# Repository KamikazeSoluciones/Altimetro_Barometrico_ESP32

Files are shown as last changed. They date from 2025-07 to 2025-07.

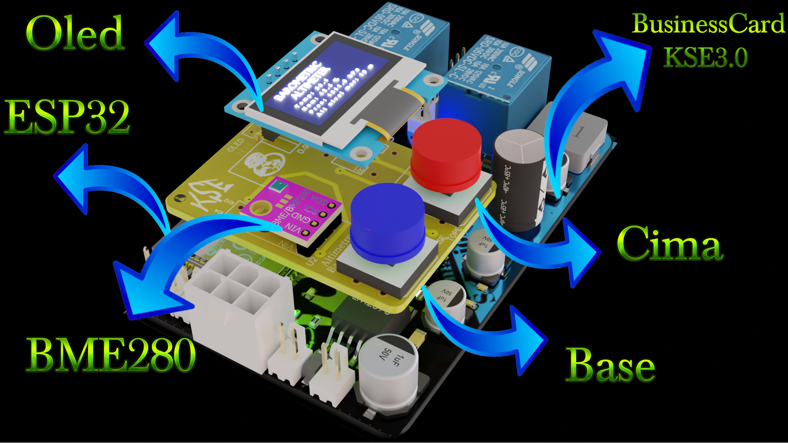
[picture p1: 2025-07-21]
Altimetro.png

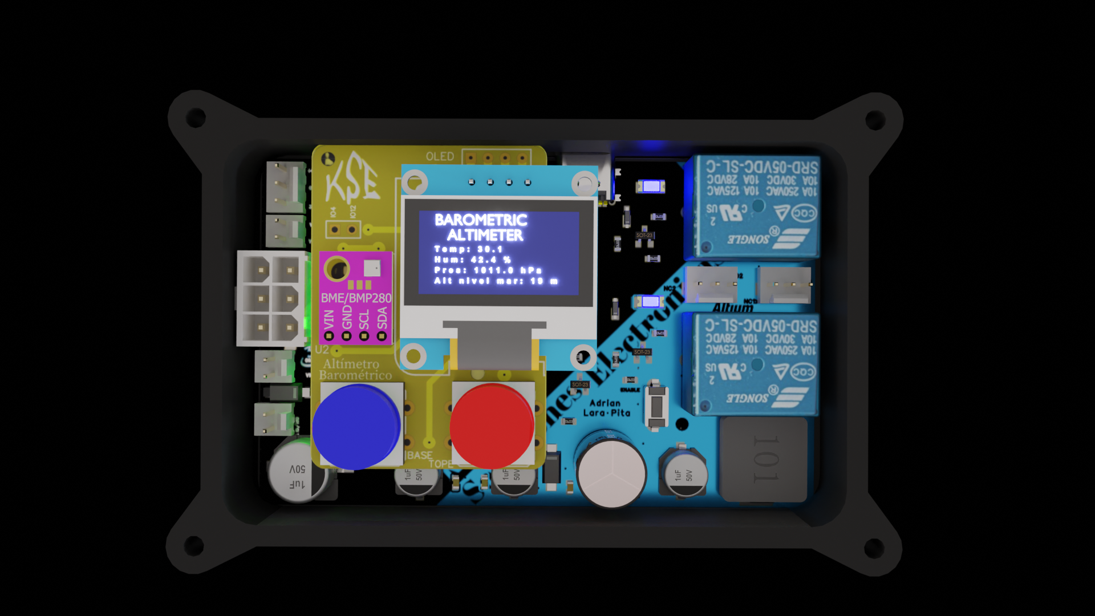
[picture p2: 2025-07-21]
render 3.png

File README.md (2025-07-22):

Altímetro Barométrico on ESP32

Este dispositivo es un proyecto experimental de altímetro barométrico diseñado para estimar la altura entre 
dos puntos mediante la diferencia de presión atmosférica, utilizando un sensor BME280 y un microcontrolador ESP32. 
La lectura se muestra en una pantalla OLED.

Este dispositivo fue probado en terreno en varios puntos icónicos de París: 
Torre Eiffel 
Arco del Triunfo.
Museo de Louvre
Río Sena

🚀 Objetivo

Explorar el uso de sensores barométricos para medir alturas reales, como una evolución de métodos tradicionales 
(por ejemplo, estimar la altura de edificios según el número de pisos). Además, es un proyecto ideal para enseñar 
física, presión atmosférica y electrónica aplicada.

📸 Ejemplo de Medición en la Torre Eiffel

- Presión atmosférica marcada en la base: 1017,6 hPa  
- Presión atmosférica marcada en el segundo piso: 1003,83 hPa  
- Altura estimada: 113,1 m  
- Altura oficial: 116 m  

🧰 Componentes utilizados


- ESP32 (Business Card Green Edition)
- Sensor BME280 (I2C)
- Pantalla OLED 128x64 (SSD1306)
- Pulsadores N.O.
- Power Bank
- Enclosure 3D impreso (modelado en SolidWorks)

⚙️ Funcionamiento

1. Al encender el dispositivo, se muestra la presión y temperatura actuales.
2. Se presiona el botón "Start" para registrar la presión inicial.
3. En otro punto, se presiona el botón "End" para registrar la nueva presión.
4. El sistema calcula la altura estimada según la fórmula barométrica.
5. Los datos se muestran en la pantalla Oled.

🧮 Fórmula usada



🛠️ Para compilar

1. Abre el código con Arduino IDE o PlatformIO.
2. Instala las siguientes bibliotecas:

   - Adafruit BME280
   - Adafruit Sensor
   - Adafruit SSD1306
3. Ajusta los pines I2C si es necesario.
4. Sube el código al ESP32 y listo.

📦 Impresión 3D
- El diseño incluye una tapa avellanada para tornillos M3.
- Archivos disponibles en formato `.step` y `.stl`.
  




✍️ Autor

Adrian Lara – Freelance en electrónica, diseño 3D y sistemas embebidos
🔗 Youtube: https://youtu.be/_3JePDyfMUw 
📞 +351 911 180 717

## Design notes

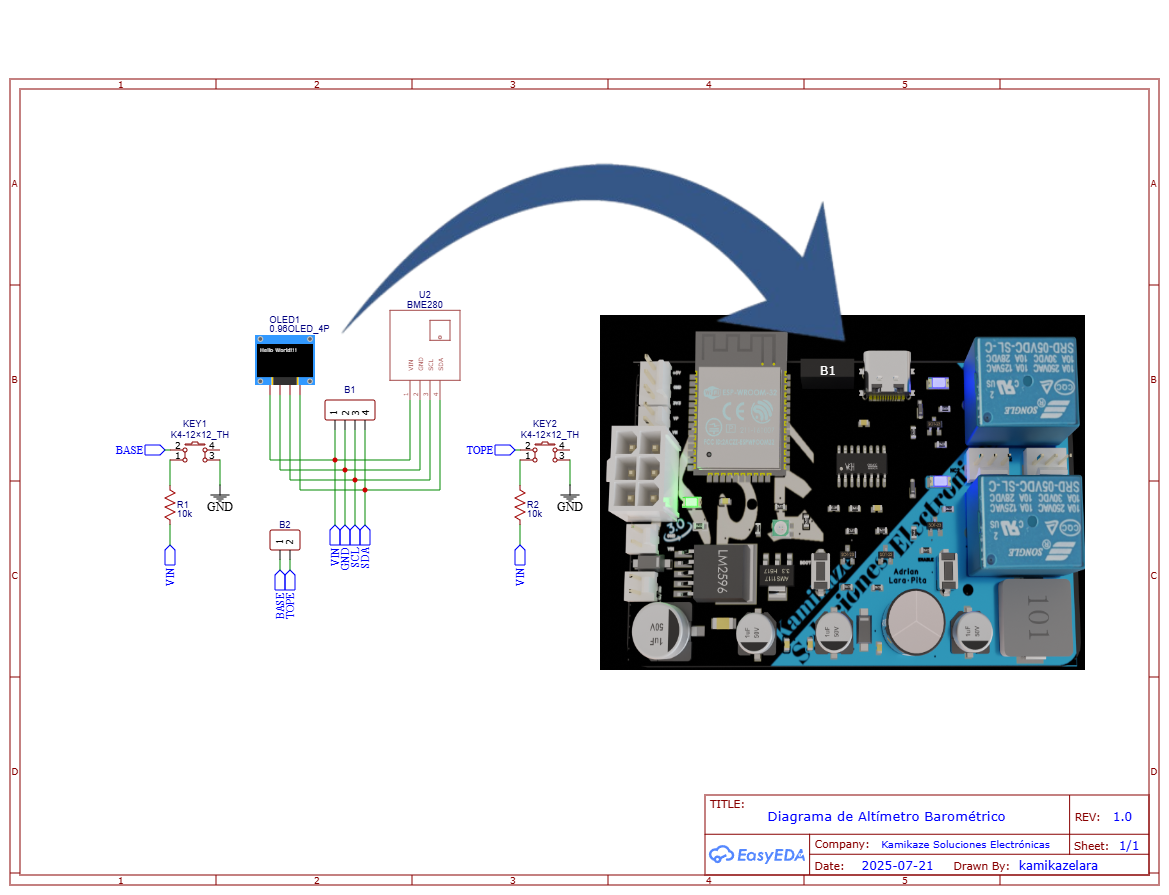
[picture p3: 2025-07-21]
Schematic_Altimetro-Barometrico_2025-07-21.png

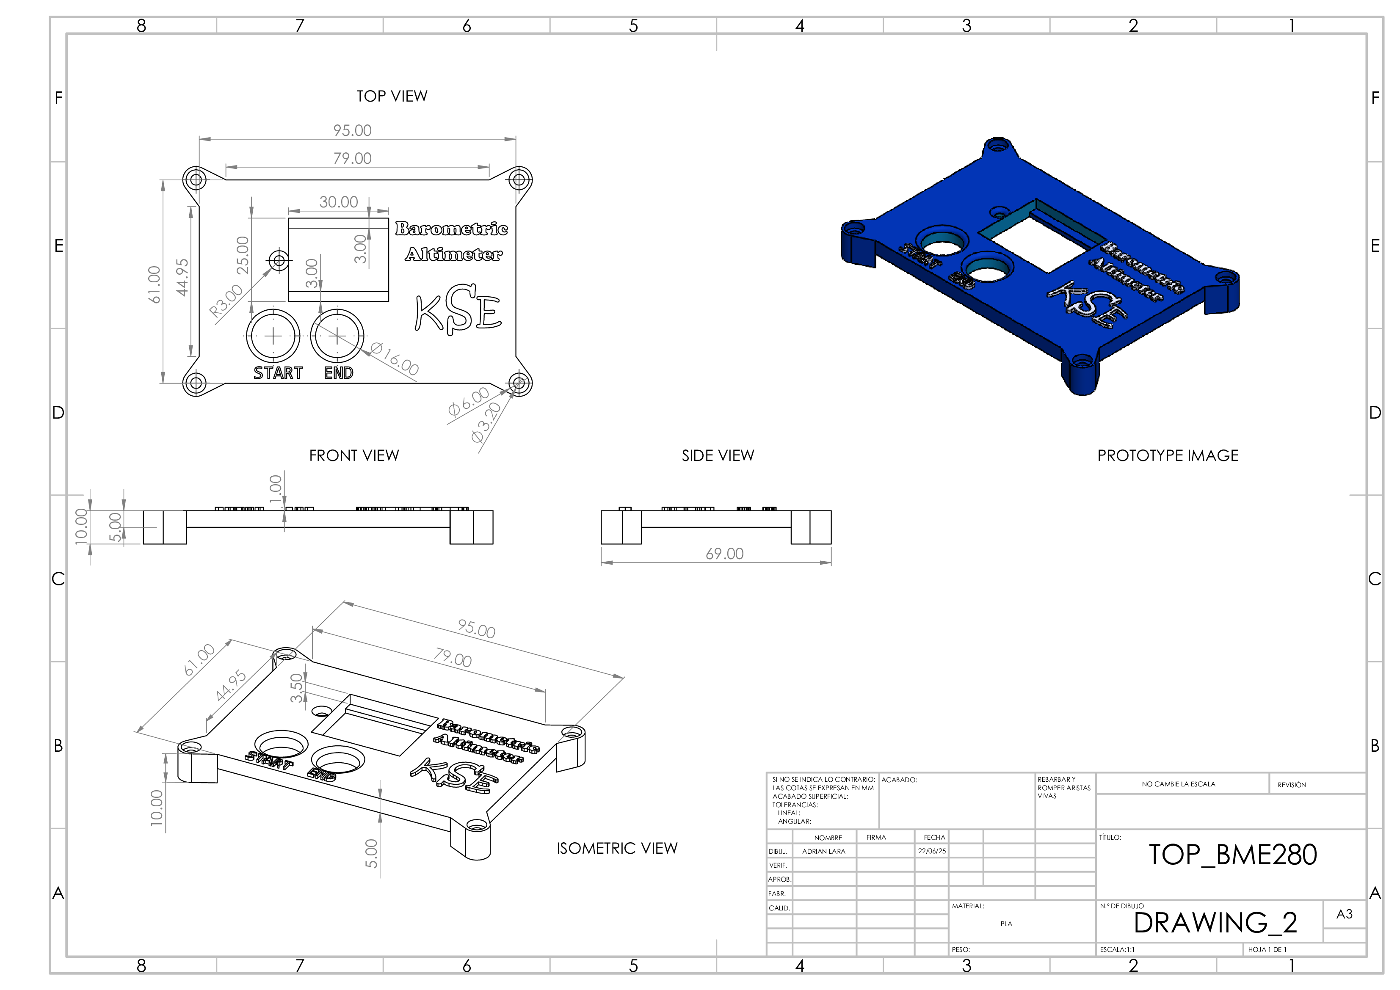
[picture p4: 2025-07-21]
Top_BME280.png

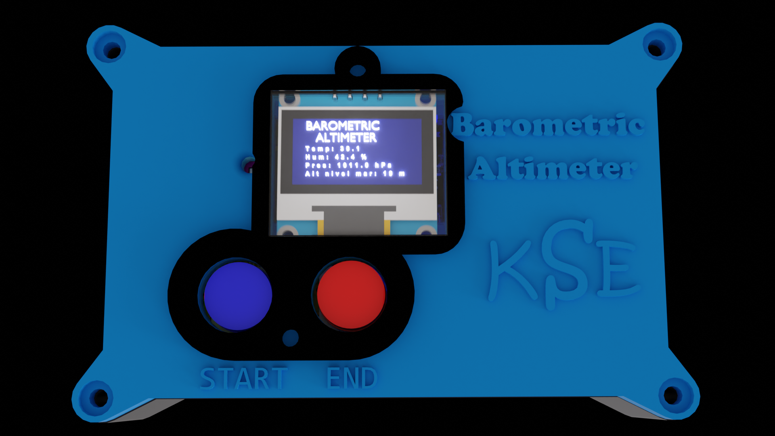
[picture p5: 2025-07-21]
render3.png

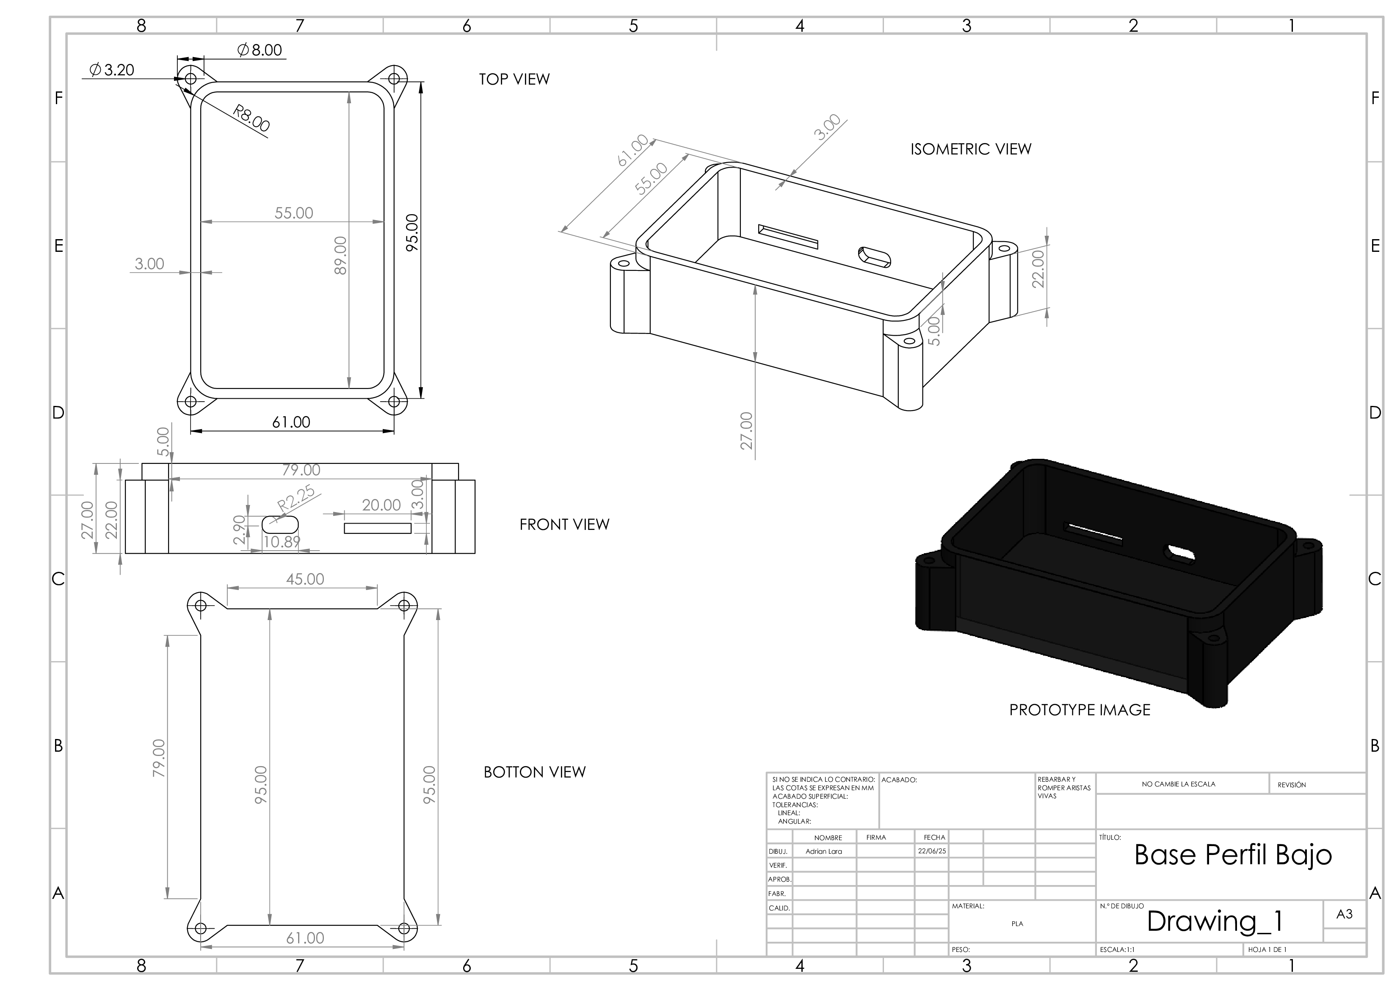
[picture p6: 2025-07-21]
Base._Perfil_Bajo.png

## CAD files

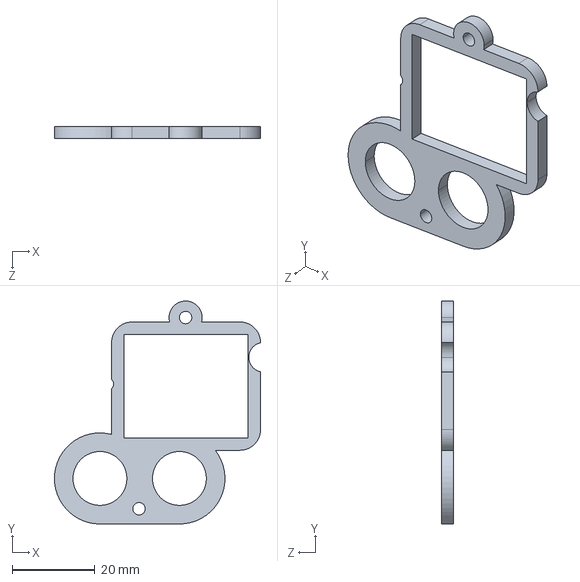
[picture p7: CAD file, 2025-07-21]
Marco Oled.STEP
49.8 x 53.9 x 3.00 mm

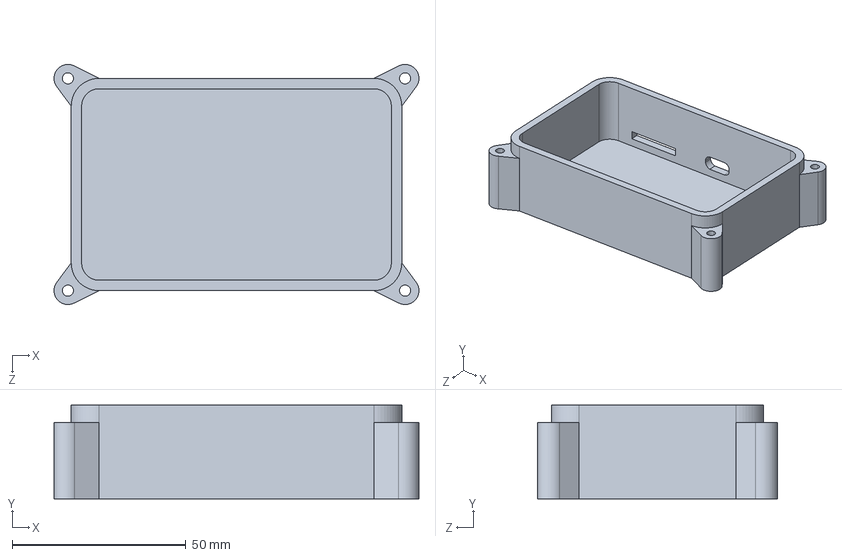
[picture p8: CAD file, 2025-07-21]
Base._Perfil_Bajo.STEP
104.9 x 27.0 x 69.0 mm

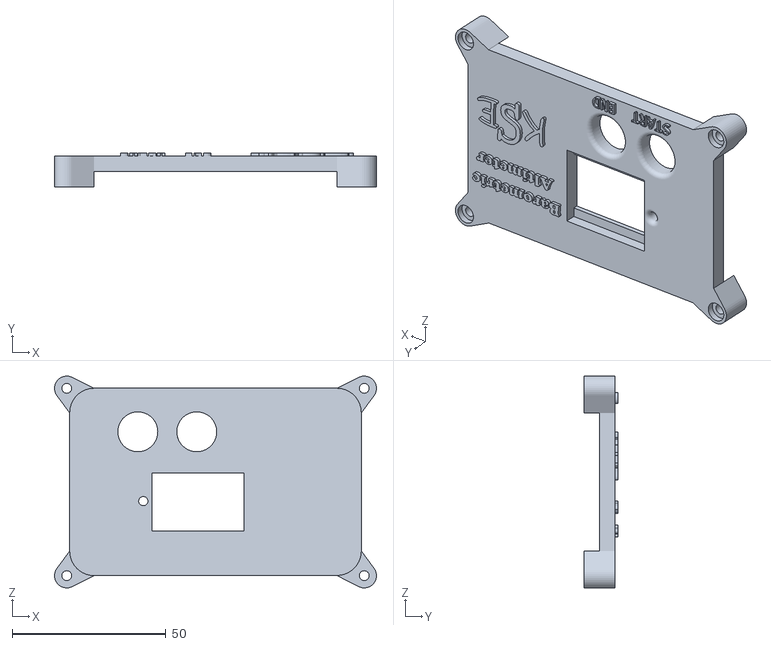
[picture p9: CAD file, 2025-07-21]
Top_BME280.STL
104.9 x 11.0 x 69.0

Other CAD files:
Base._Perfil_Bajo.STL
Marco Oled.STL

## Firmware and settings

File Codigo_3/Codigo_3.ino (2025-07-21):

#include <Wire.h>
#include <Adafruit_SSD1306.h>
#include <Adafruit_BME280.h>

#define SCREEN_WIDTH 128
#define SCREEN_HEIGHT 64
#define OLED_RESET     -1
Adafruit_SSD1306 display(SCREEN_WIDTH, SCREEN_HEIGHT, &Wire, OLED_RESET);

Adafruit_BME280 bme;

#define BUTTON_BASE 12
#define BUTTON_TOP  4

float basePressure = 0.0;
float topPressure = 0.0;
float relativeAltitude = 0.0;
bool baseSet = false;
bool topSet = false;

void setup() {
  Serial.begin(115200);
  pinMode(BUTTON_BASE, INPUT_PULLUP);
  pinMode(BUTTON_TOP, INPUT_PULLUP);

  if (!display.begin(SSD1306_SWITCHCAPVCC, 0x3C)) {
    Serial.println(F("OLED não encontrada"));
    while (true);
  }

  if (!bme.begin(0x76)) {
    Serial.println(F("BME280 não encontrado"));
    while (true);
  }

  display.clearDisplay();
  display.setTextColor(SSD1306_WHITE);
  display.setTextSize(1);
  display.setCursor(15, 0);
  display.println("BAROMETRIC");
  display.setCursor(20, 12);
  display.println("ALTIMETER");
  display.display();
  delay(2000);
}

void loop() {
  float temp = bme.readTemperature();
  float pres = bme.readPressure() / 100.0F; // hPa
  float hum = bme.readHumidity();
  float altSea = 44330.0 * (1.0 - pow(pres / 1013.25, 0.1903)); // Altitud nivel mar

  // RESET si ambos botones están presionados
  if (digitalRead(BUTTON_BASE) == LOW && digitalRead(BUTTON_TOP) == LOW) {
    basePressure = 0;
    topPressure = 0;
    relativeAltitude = 0;
    baseSet = false;
    topSet = false;

    display.clearDisplay();
    display.setCursor(0, 0);
    display.println("BAROMETRIC");
    display.setCursor(0, 16);
    display.println("ALTIMETER");
    display.setCursor(0, 40);
    display.println("RESET realizado");
    display.display();
    delay(1500);
  } 
  else if (digitalRead(BUTTON_BASE) == LOW && !baseSet) {
    basePressure = pres;
    baseSet = true;

    display.clearDisplay();
    display.setCursor(0, 0);
    display.println("Base marcada:");
    display.setCursor(0, 20);
    display.print(basePressure);
    display.println(" hPa");
    display.display();
    delay(1000);
  } 
  else if (digitalRead(BUTTON_TOP) == LOW && baseSet && !topSet) {
    topPressure = pres;
    topSet = true;
    relativeAltitude = 44330.0 * (1.0 - pow(topPressure / basePressure, 0.1903));

    display.clearDisplay();
    display.setCursor(0, 0);
    display.println("Cima marcada:");
    display.setCursor(0, 16);
    display.print(topPressure);
    display.println(" hPa");
    display.setCursor(0, 36);
    display.print("Altura: ");
    display.print(relativeAltitude, 1);
    display.println(" m");
    display.display();
    delay(2000);
  }

  // Vista en reposo: datos + altitud nivel mar
  if (!baseSet || !topSet) {
    display.clearDisplay();
    display.setCursor(0, 0);
    display.println(" BAROMETRIC");
    display.setCursor(0, 12);
    display.println("  ALTIMETER");

    display.setCursor(0, 26);
    display.print("Temp: ");
    display.print(temp, 1);
    display.println(" C");

    display.setCursor(0, 36);
    display.print("Hum:  ");
    display.print(hum, 1);
    display.println(" %");

    display.setCursor(0, 46);
    display.print("Pres: ");
    display.print(pres, 1);
    display.println(" hPa");

    display.setCursor(0, 56);
    display.print("Alt nivel mar: ");
    display.print(altSea, 0);
    display.println(" m");
    display.display();
  }

  delay(500);
}
